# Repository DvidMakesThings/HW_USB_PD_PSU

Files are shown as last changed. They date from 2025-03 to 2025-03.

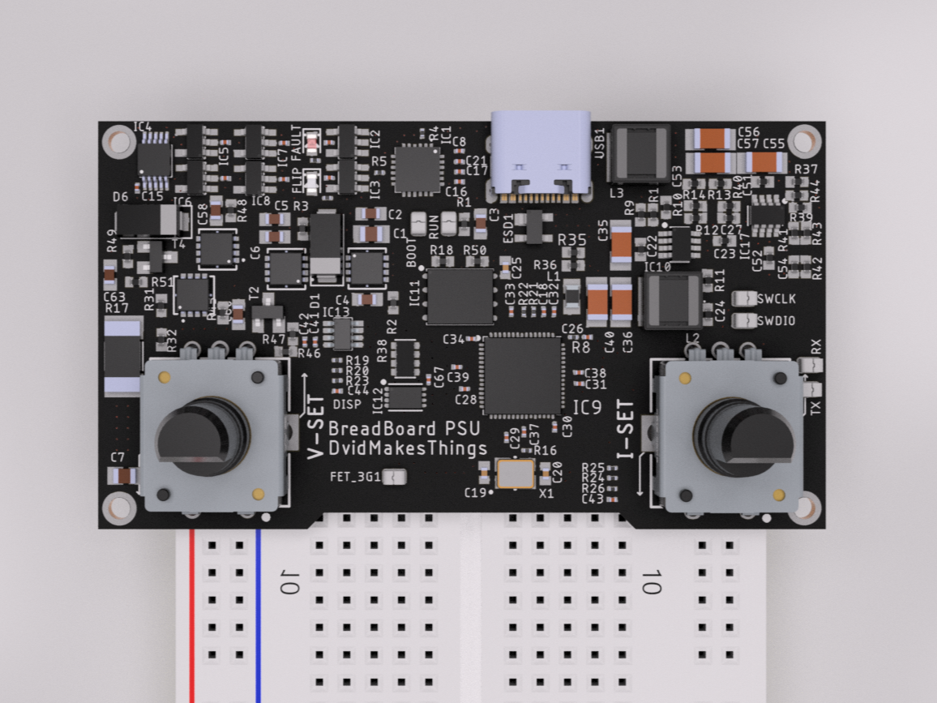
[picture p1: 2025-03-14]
images/USB-PD-PSU-3D-3.png

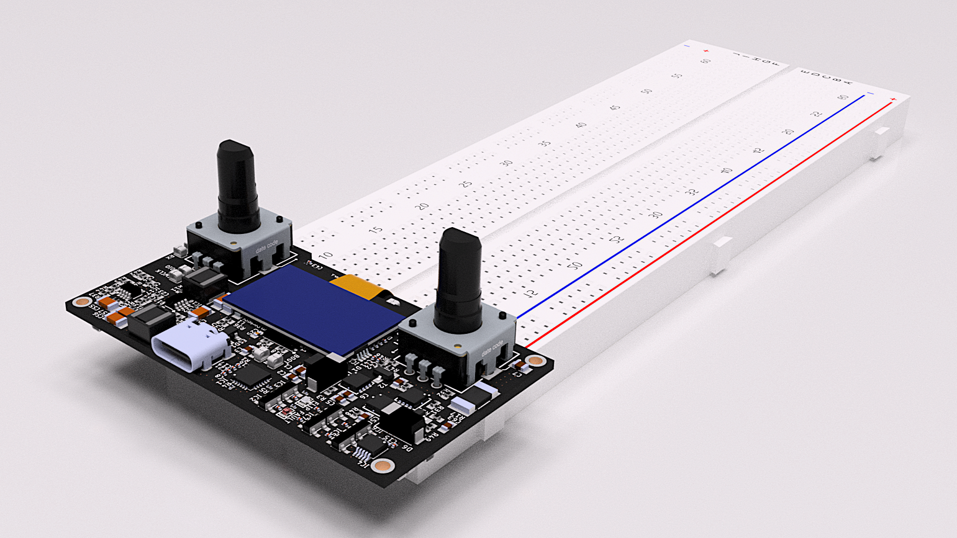
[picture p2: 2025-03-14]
images/USB-PD-PSU-3D-1.png

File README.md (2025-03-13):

# USB-PD-PSU Project

## Contents
This folder contains all the documents related to the USB-PD-PSU project.

## Usage
To use the files in this project, navigate to the respective directories and follow the instructions provided in each document.

## License
This project is licensed under the GPL-3.0 License. See the [LICENSE](LICENSE) file for details.

## Contact
For questions or feedback:
- Email: [s.dvid@hotmail.com](mailto:s.dvid@hotmail.com)
- GitHub: [DvidMakesThings](https://github.com/DvidMakesThings)

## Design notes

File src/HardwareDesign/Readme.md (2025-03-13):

# # USB-PD-PSU Project Hardware Design Files

## Contents
This folder contains the hardware design files for the USB-PD-PSU project. The main components include:
- Schematic diagrams
- PCB layouts
- Bill of Materials (BOM)
- Gerber files

## Usage
To use these hardware design files:
1. Open the schematic diagrams and PCB layouts using EAGLE software.
2. Review the Bill of Materials for required components.
3. Follow the design files to assemble and test the hardware.
4. Use the Gerber files for PCB manufacturing.

## License
This project is licensed under the GPL-3.0 License. See the [LICENSE](LICENSE) file for details.

## Contact
For questions or feedback:
- Email: [s.dvid@hotmail.com](mailto:s.dvid@hotmail.com)
- GitHub: [DvidMakesThings](https://github.com/DvidMakesThings)

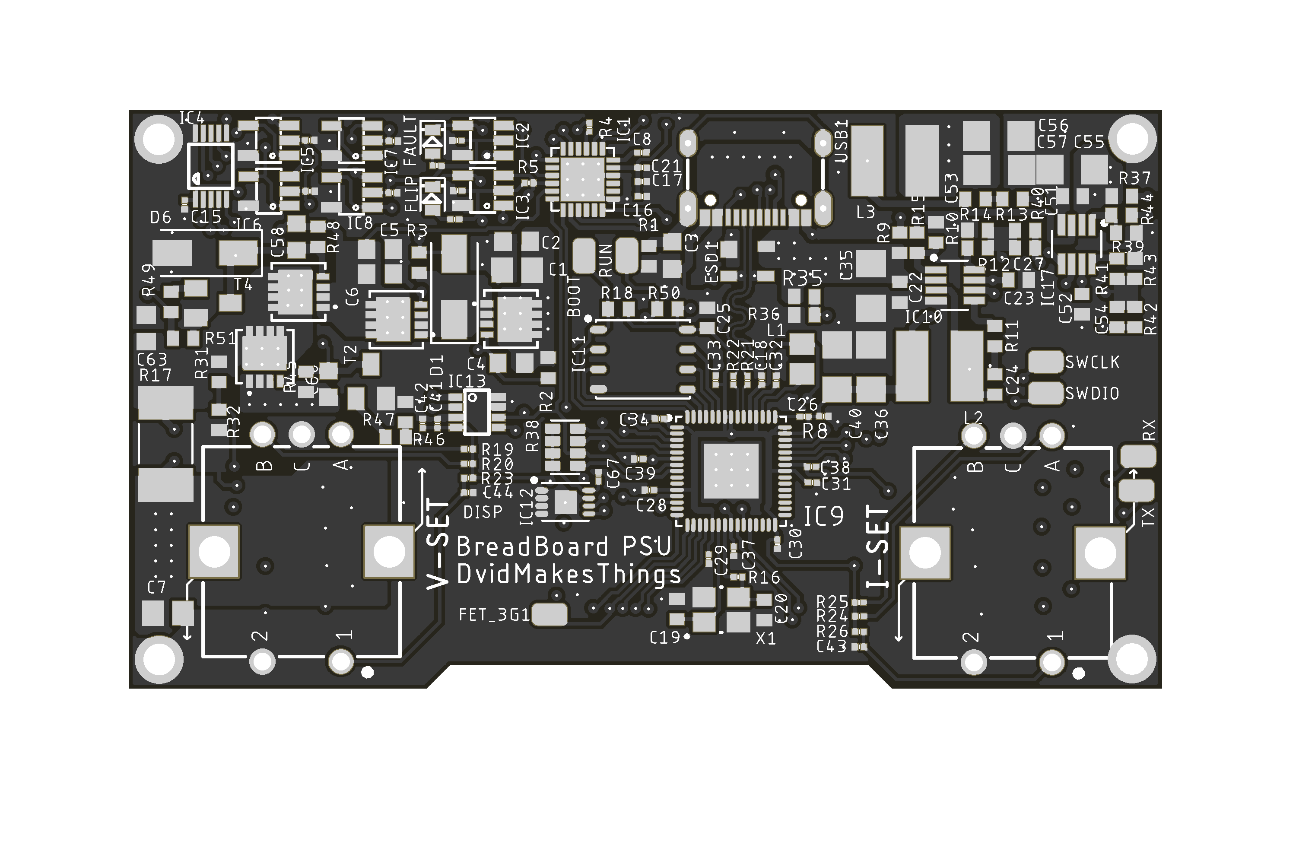
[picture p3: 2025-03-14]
images/USB-PD-PSU-Top.png

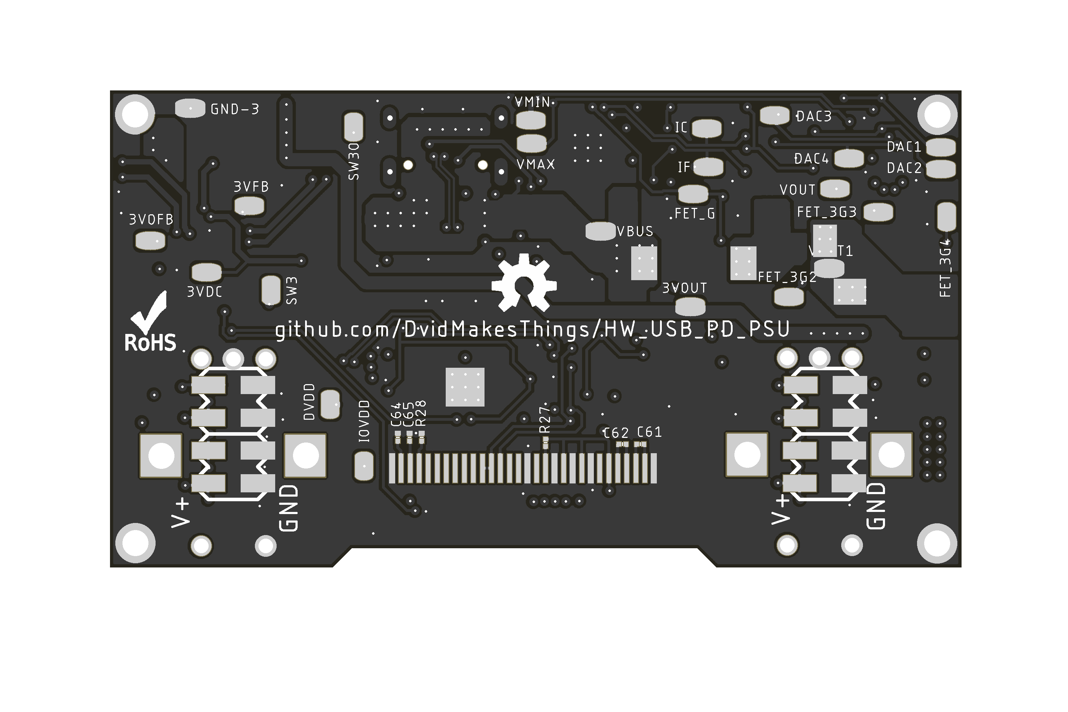
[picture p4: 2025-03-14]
images/USB-PD-PSU-Bottom.png

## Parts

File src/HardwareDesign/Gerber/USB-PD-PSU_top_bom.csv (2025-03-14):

Comment | Designator | Footprint | LCSC Part #
 | IC9 | QFN40P700X700X85-61T340N
 | USB1 | USB-C
0.1R 1% | R17 | 2512
1K | R4 R6 R7 R16 | R0201
1K | R32 R36 | 0402
1M | R1 | 0402
1uF | C4 | C0603
1uF | C8 C21 C42 | 0201
1uF | C58 C60 | C0603
3.3uH LQM21PN3R3MGRD | L1 | 0805
4.2uH | L2 L3 | SRR5228A
4.7K | R5 | R0201
4.7uF | C18 C26 C39 | 0201
4D03WGJ0332T5E | R38 | 742C083103JP
7.5K | R10 R39 | 0402
10K | R2 R18 | 0402
10K | R19 R20 R23 R24 R25 R26 | R0201
10K | R31 R35 R45 R47 R48 R50 R51 | 0402
10R | R11 R40 R46 R49 | 0402
10uF | C1 | C0805
10uF | C15 | 0201
10uF 50V | C6 | C0603
10uF 50V | C7 | C0805
10uF 50V | C63 | C0603
12.7K | R14 R43 | 0402
12MHz | X1 | WE-XTAL_CFPX-180
15pF | C19 C20 | C0402
22uF - 10V | C36 C40 C56 C57 | C1206
22uF 25V | C35 C55 | C1206
27R | R8 R21 R22 | R0201
33K | R12 R41 | 0402
33pF | C27 C54 | 0402
40.2K | R13 R42 | 0402
49.9K | R3 | 0402
100K | R15 R44 | 0402
100nF | C2 C3 | C0603
100nF | C9 C10 C11 C12 C13 C14 C16 C17 | 0201
100nF | C22 C23 C24 | 0402
100nF | C25 | C0402
100nF | C28 C29 C30 C31 C32 C33 C34 C37 C38 C41 C43 C44 | 0201
100nF | C51 C52 C53 | 0402
100nF | C67 | 0201
100nF 50V | C5 | C0603
499K | R9 R37 | 0402
BSS138 | T2 T4 | SOT23
CAT24C512HU5IGT3 | IC12 | SON50P300X200X50-9T130X140N
CHIP-FLAT-B_0603 | FLIP | LEDC1608X55N_FLAT-B
CHIP-FLAT-R_0603 | FAULT | LEDC1608X55N_FLAT-R
CYPD3177 | IC1 | QFN24
DMP3013SFV | MOSFET1 MOSFET2 MOSFET3 MOSFET4 | POWERDI3333-8_UX_DIO-L
INA219BIDCNT | IC13 | SOT23-8
MCP4728 | IC4 | MSOP10
MCP6001RT-I/OT | IC2 IC3 IC5 IC6 IC7 IC8 | SOT23-5
MP2315S | IC10 IC17 | SOT65P280X110-8N
SMBJ5929B | D1 D6 | DIOM5226X290N
SP0503BAHTG-ES | ESD1 | SOT143
TP | BOOT FET_3G1 RUN RX SWCLK SWDIO TX | TP
W25Q128JVPIQ | IC11 | SON127P600X500X75-8N

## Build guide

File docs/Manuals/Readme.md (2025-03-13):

# USB-PD-PSU Project Manuals

## Contents
- Manuals

## Usage
This folder contains documentation and manuals for the USB-PD-PSU project.

## License
This project is licensed under the GPL-3.0 License. See the [LICENSE](LICENSE) file for details.

## Contact
For questions or feedback:
- Email: [s.dvid@hotmail.com](mailto:s.dvid@hotmail.com)
- GitHub: [DvidMakesThings](https://github.com/DvidMakesThings)

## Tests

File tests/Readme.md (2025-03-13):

# USB-PD-PSU Project Test files

This folder contains the main test files for the USB-PD-PSU project.

## Contents
- Various test scripts and files for the USB-PD-PSU project.

## Usage
1. Clone the repository.
2. Navigate to this folder.
3. Run the test scripts as needed.

## License
This project is licensed under the GPL-3.0 License. See the [LICENSE](LICENSE) file for details.

## Contact
For questions or feedback:
- Email: [s.dvid@hotmail.com](mailto:s.dvid@hotmail.com)
- GitHub: [DvidMakesThings](https://github.com/DvidMakesThings)

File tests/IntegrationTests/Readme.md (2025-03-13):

# # USB-PD-PSU Project Integration Tests

This folder contains integration tests for the USB-PD-PSU project.

## Contents

- Various integration test scripts and resources.

## Usage

1. Clone the repository.
2. Navigate to this folder.
3. Run the integration tests using your preferred testing framework.

## License
This project is licensed under the GPL-3.0 License. See the [LICENSE](LICENSE) file for details.

## Contact
For questions or feedback:
- Email: [s.dvid@hotmail.com](mailto:s.dvid@hotmail.com)
- GitHub: [DvidMakesThings](https://github.com/DvidMakesThings)

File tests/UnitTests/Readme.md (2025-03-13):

# USB-PD-PSU Project Unit Tests

## Contents
This folder contains unit tests for the USB-PD-PSU project.

## Usage
To run the unit tests, navigate to this directory and execute the test scripts using your preferred testing framework.

## License
This project is licensed under the GPL-3.0 License. See the [LICENSE](LICENSE) file for details.

## Contact
For questions or feedback:
- Email: [s.dvid@hotmail.com](mailto:s.dvid@hotmail.com)
- GitHub: [DvidMakesThings](https://github.com/DvidMakesThings)

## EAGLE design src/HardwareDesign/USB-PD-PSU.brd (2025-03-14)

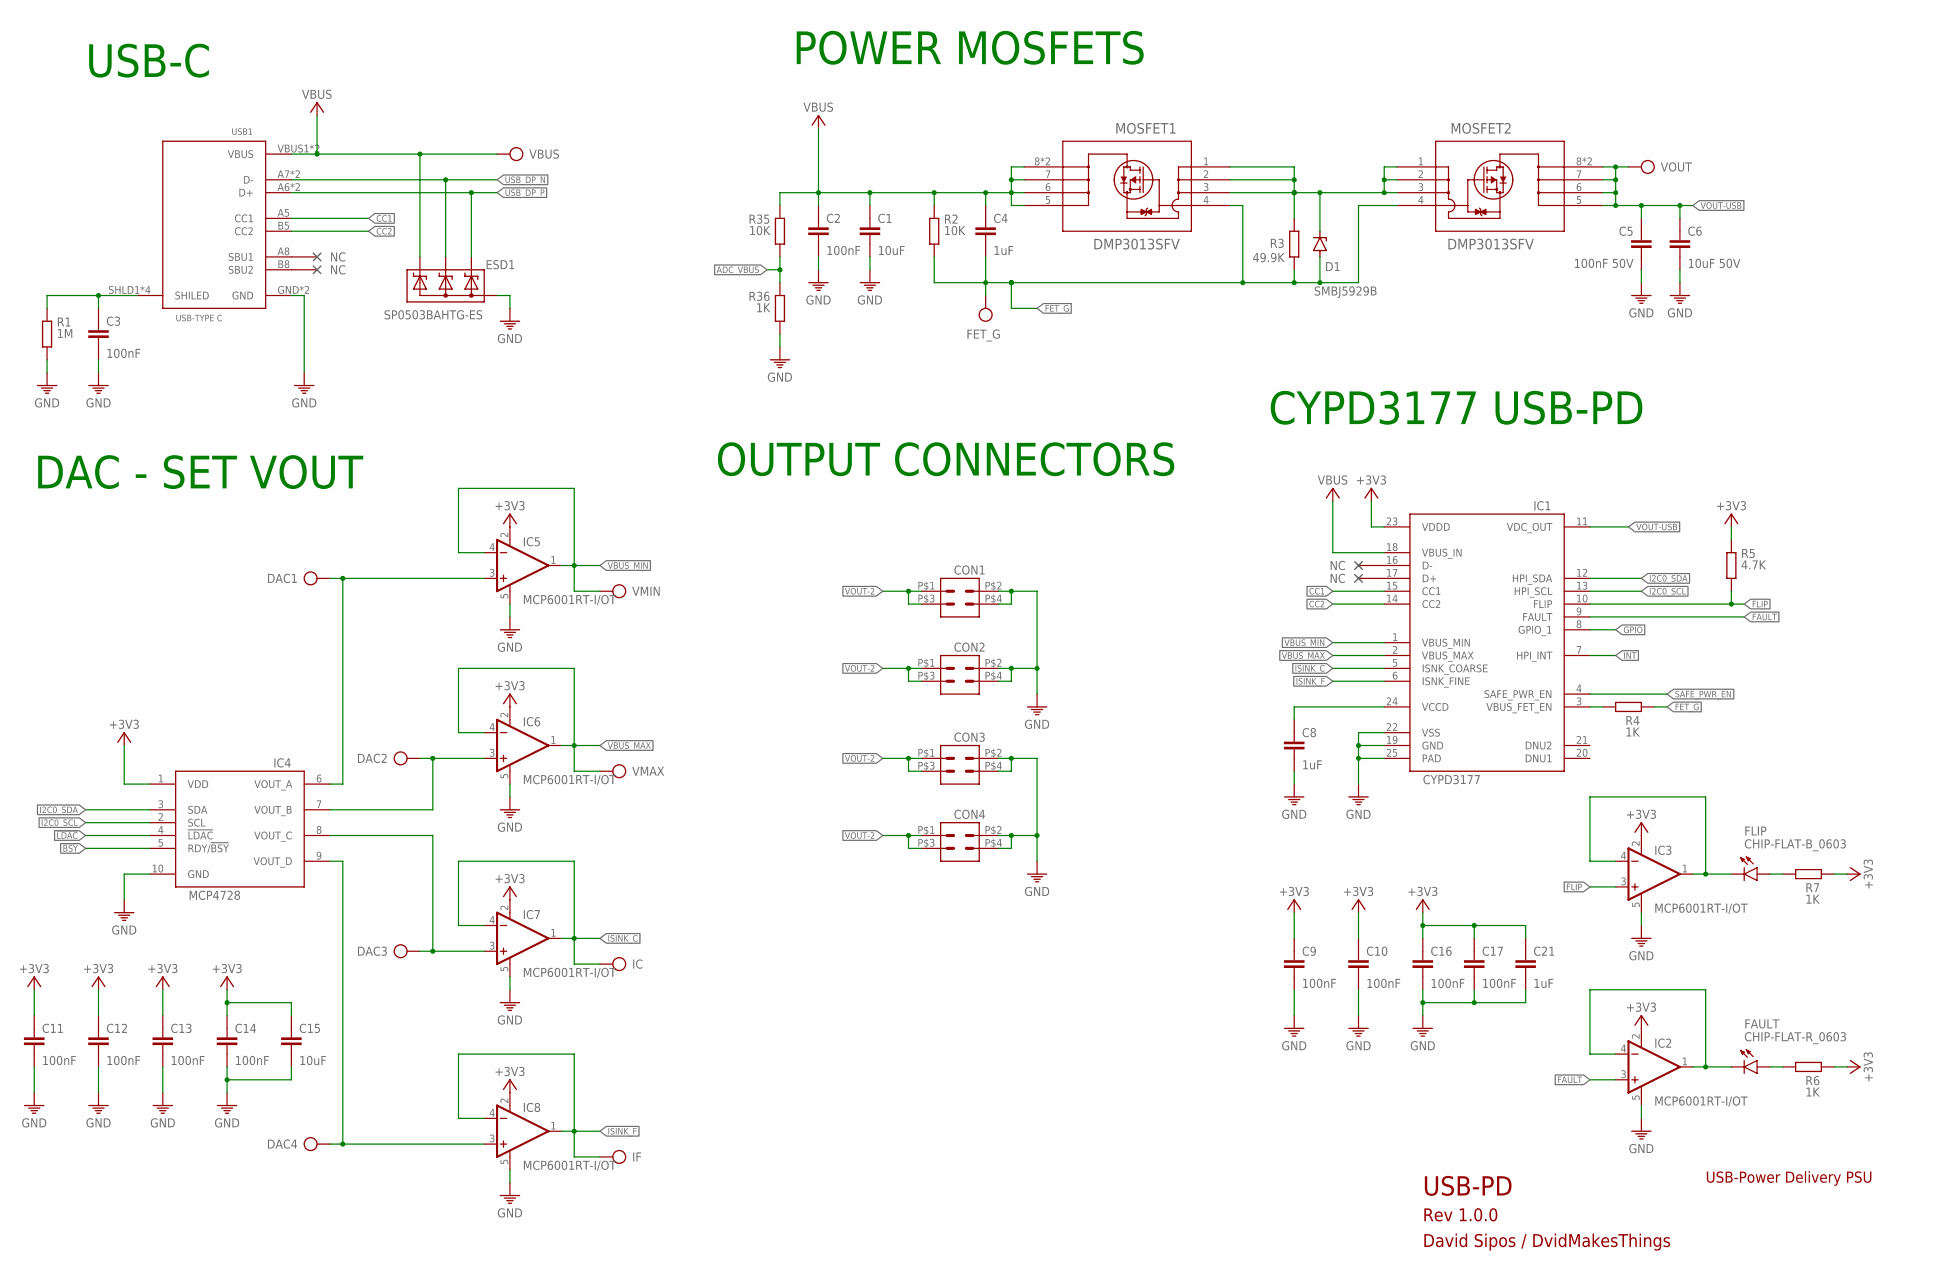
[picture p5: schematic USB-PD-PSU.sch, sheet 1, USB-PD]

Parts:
C1: 10uF; C0805
C2, C3: 100nF; C0603
C4: 1uF; C0603
C5: 100nF 50V; C0603
C6: 10uF 50V; C0603
C8, C21: 1uF; 0201
C9, C10, C11, C12, C13, C14, C16, C17: 100nF; 0201
C15: 10uF; 0201
CON1, CON2, CON3, CON4: CON-2X2SMD; 2X2_SMD
D1: SMBJ5929B; DIOM5226X290N
DAC1, DAC2, DAC3, DAC4: TP
ESD1: SP0503BAHTG-ES; SOT143
FAULT: CHIP-FLAT-R_0603; LEDC1608X55N_FLAT-R
FET_G: TP
FLIP: CHIP-FLAT-B_0603; LEDC1608X55N_FLAT-B
IC: TP
IC1: CYPD3177; QFN24
IC2, IC3, IC5, IC6, IC7, IC8: MCP6001RT-I/OT; SOT23-5
IC4: MCP4728; MSOP10
IF: TP
MOSFET1, MOSFET2: DMP3013SFV; POWERDI3333-8_UX_DIO-L
R1: 1M; 0402
R2, R35: 10K; 0402
R3: 49.9K; 0402
R4, R6, R7: 1K; R0201
R5: 4.7K; R0201
R36: 1K; 0402
USB1: USB_C-THT; USB-C
VBUS: TP
VMAX: TP
VMIN: TP
VOUT: TP

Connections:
!BSY: IC4.5 (RDY/!BSY); also elsewhere on the board
!LDAC: IC4.4 (!LDAC); also elsewhere on the board
+3V3: C9.1, C10.1, C11.1, C12.1, C13.1, C14.1, C15.1, C16.1, C17.1, C21.1, IC1.23 (VDDD), IC2.2 (V+), IC3.2 (V+), IC4.1 (VDD), IC5.2 (V+), IC6.2 (V+), IC7.2 (V+), IC8.2 (V+), R5.1, R6.1, R7.1; also elsewhere on the board
ADC_VBUS: R35.2, R36.1; also elsewhere on the board
CC1: IC1.15 (CC1), USB1.A5 (CC1)
CC2: IC1.14 (CC2), USB1.B5 (CC2)
FAULT: IC1.9 (FAULT), IC2.3 (+IN); also elsewhere on the board
FET_G: C4.2, D1.2 (A), FET_G.TP, MOSFET1.4 (G), MOSFET2.4 (G), R2.2, R3.2, R4.1
FLIP: IC1.10 (FLIP), IC3.3 (+IN), R5.2; also elsewhere on the board
GND: C1.2, C2.2, C3.2, C5.2, C6.2, C8.2, C9.2, C10.2, C11.2, C12.2, C13.2, C14.2, C15.2, C16.2, C17.2, C21.2, CON1.P$2 (2), CON1.P$4 (4), CON2.P$2 (2), CON2.P$4 (4), CON3.P$2 (2), CON3.P$4 (4), CON4.P$2 (2), CON4.P$4 (4), ESD1.1 (A), IC1.19 (GND), IC1.22 (VSS), IC1.25 (PAD), IC2.5 (V-), IC3.5 (V-), IC4.10 (GND), IC5.5 (V-), IC6.5 (V-), IC7.5 (V-), IC8.5 (V-), R1.2, R36.2, USB1.GND, USB1.GND2 (GND); also elsewhere on the board
GPIO: IC1.8 (GPIO_1)
I2C0_SCL: IC1.13 (HPI_SCL), IC4.2 (SCL); also elsewhere on the board
I2C0_SDA: IC1.12 (HPI_SDA), IC4.3 (SDA); also elsewhere on the board
INT: IC1.7 (HPI_INT); also elsewhere on the board
ISINK_C: IC.TP, IC1.5 (ISNK_COARSE), IC7.1 (OUT), IC7.4 (-IN)
ISINK_F: IC1.6 (ISNK_FINE), IC8.1 (OUT), IC8.4 (-IN), IF.TP
unnamed: C3.1, R1.1, USB1.SHLD1 (SHILED), USB1.SHLD2 (SHILED), USB1.SHLD3 (SHILED), USB1.SHLD4 (SHILED)
unnamed: FLIP.C, IC3.1 (OUT), IC3.4 (-IN)
unnamed: C8.1, IC1.24 (VCCD)
unnamed: IC1.3 (VBUS_FET_EN), R4.2
unnamed: D1.1 (C), MOSFET1.1 (S_2), MOSFET1.2 (S_3), MOSFET1.3 (S), MOSFET2.1 (S_2), MOSFET2.2 (S_3), MOSFET2.3 (S), R3.1
unnamed: FAULT.C, IC2.1 (OUT), IC2.4 (-IN)
unnamed: FLIP.A, R7.2
unnamed: FAULT.A, R6.2
unnamed: DAC1.TP, IC4.6 (VOUT_A), IC5.3 (+IN)
unnamed: DAC2.TP, IC4.7 (VOUT_B), IC6.3 (+IN)
unnamed: DAC3.TP, IC4.8 (VOUT_C), IC7.3 (+IN)
unnamed: DAC4.TP, IC4.9 (VOUT_D), IC8.3 (+IN)
SAFE_PWR_EN: IC1.4 (SAFE_PWR_EN)
USB_DP_N: ESD1.3 (C2), USB1.A7 (D-), USB1.B7 (D-); also elsewhere on the board
USB_DP_P: ESD1.2 (C1), USB1.A6 (D+), USB1.B6 (D+); also elsewhere on the board
VBUS: C1.1, C2.1, C4.1, ESD1.4 (C3), IC1.18 (VBUS_IN), MOSFET1.5 (D_2), MOSFET1.6 (D_3), MOSFET1.7 (D_4), MOSFET1.8 (D), MOSFET1.9 (D), R2.1, R35.1, USB1.VBUS1 (VBUS), USB1.VBUS2 (VBUS), VBUS.TP; also elsewhere on the board
VBUS_MAX: IC1.2 (VBUS_MAX), IC6.1 (OUT), IC6.4 (-IN), VMAX.TP
VBUS_MIN: IC1.1 (VBUS_MIN), IC5.1 (OUT), IC5.4 (-IN), VMIN.TP
VOUT-2: CON1.P$1 (1), CON1.P$3 (3), CON2.P$1 (1), CON2.P$3 (3), CON3.P$1 (1), CON3.P$3 (3), CON4.P$1 (1), CON4.P$3 (3); also elsewhere on the board
VOUT-USB: C5.1, C6.1, IC1.11 (VDC_OUT), MOSFET2.5 (D_2), MOSFET2.6 (D_3), MOSFET2.7 (D_4), MOSFET2.8 (D), MOSFET2.9 (D), VOUT.TP; also elsewhere on the board

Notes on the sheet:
CYPD3177 USB-PD
USB-C
POWER MOSFETS
DAC - SET VOUT
USB-PD
Rev 1.0.0
David Sipos / DvidMakesThings
USB-Power Delivery PSU
OUTPUT CONNECTORS

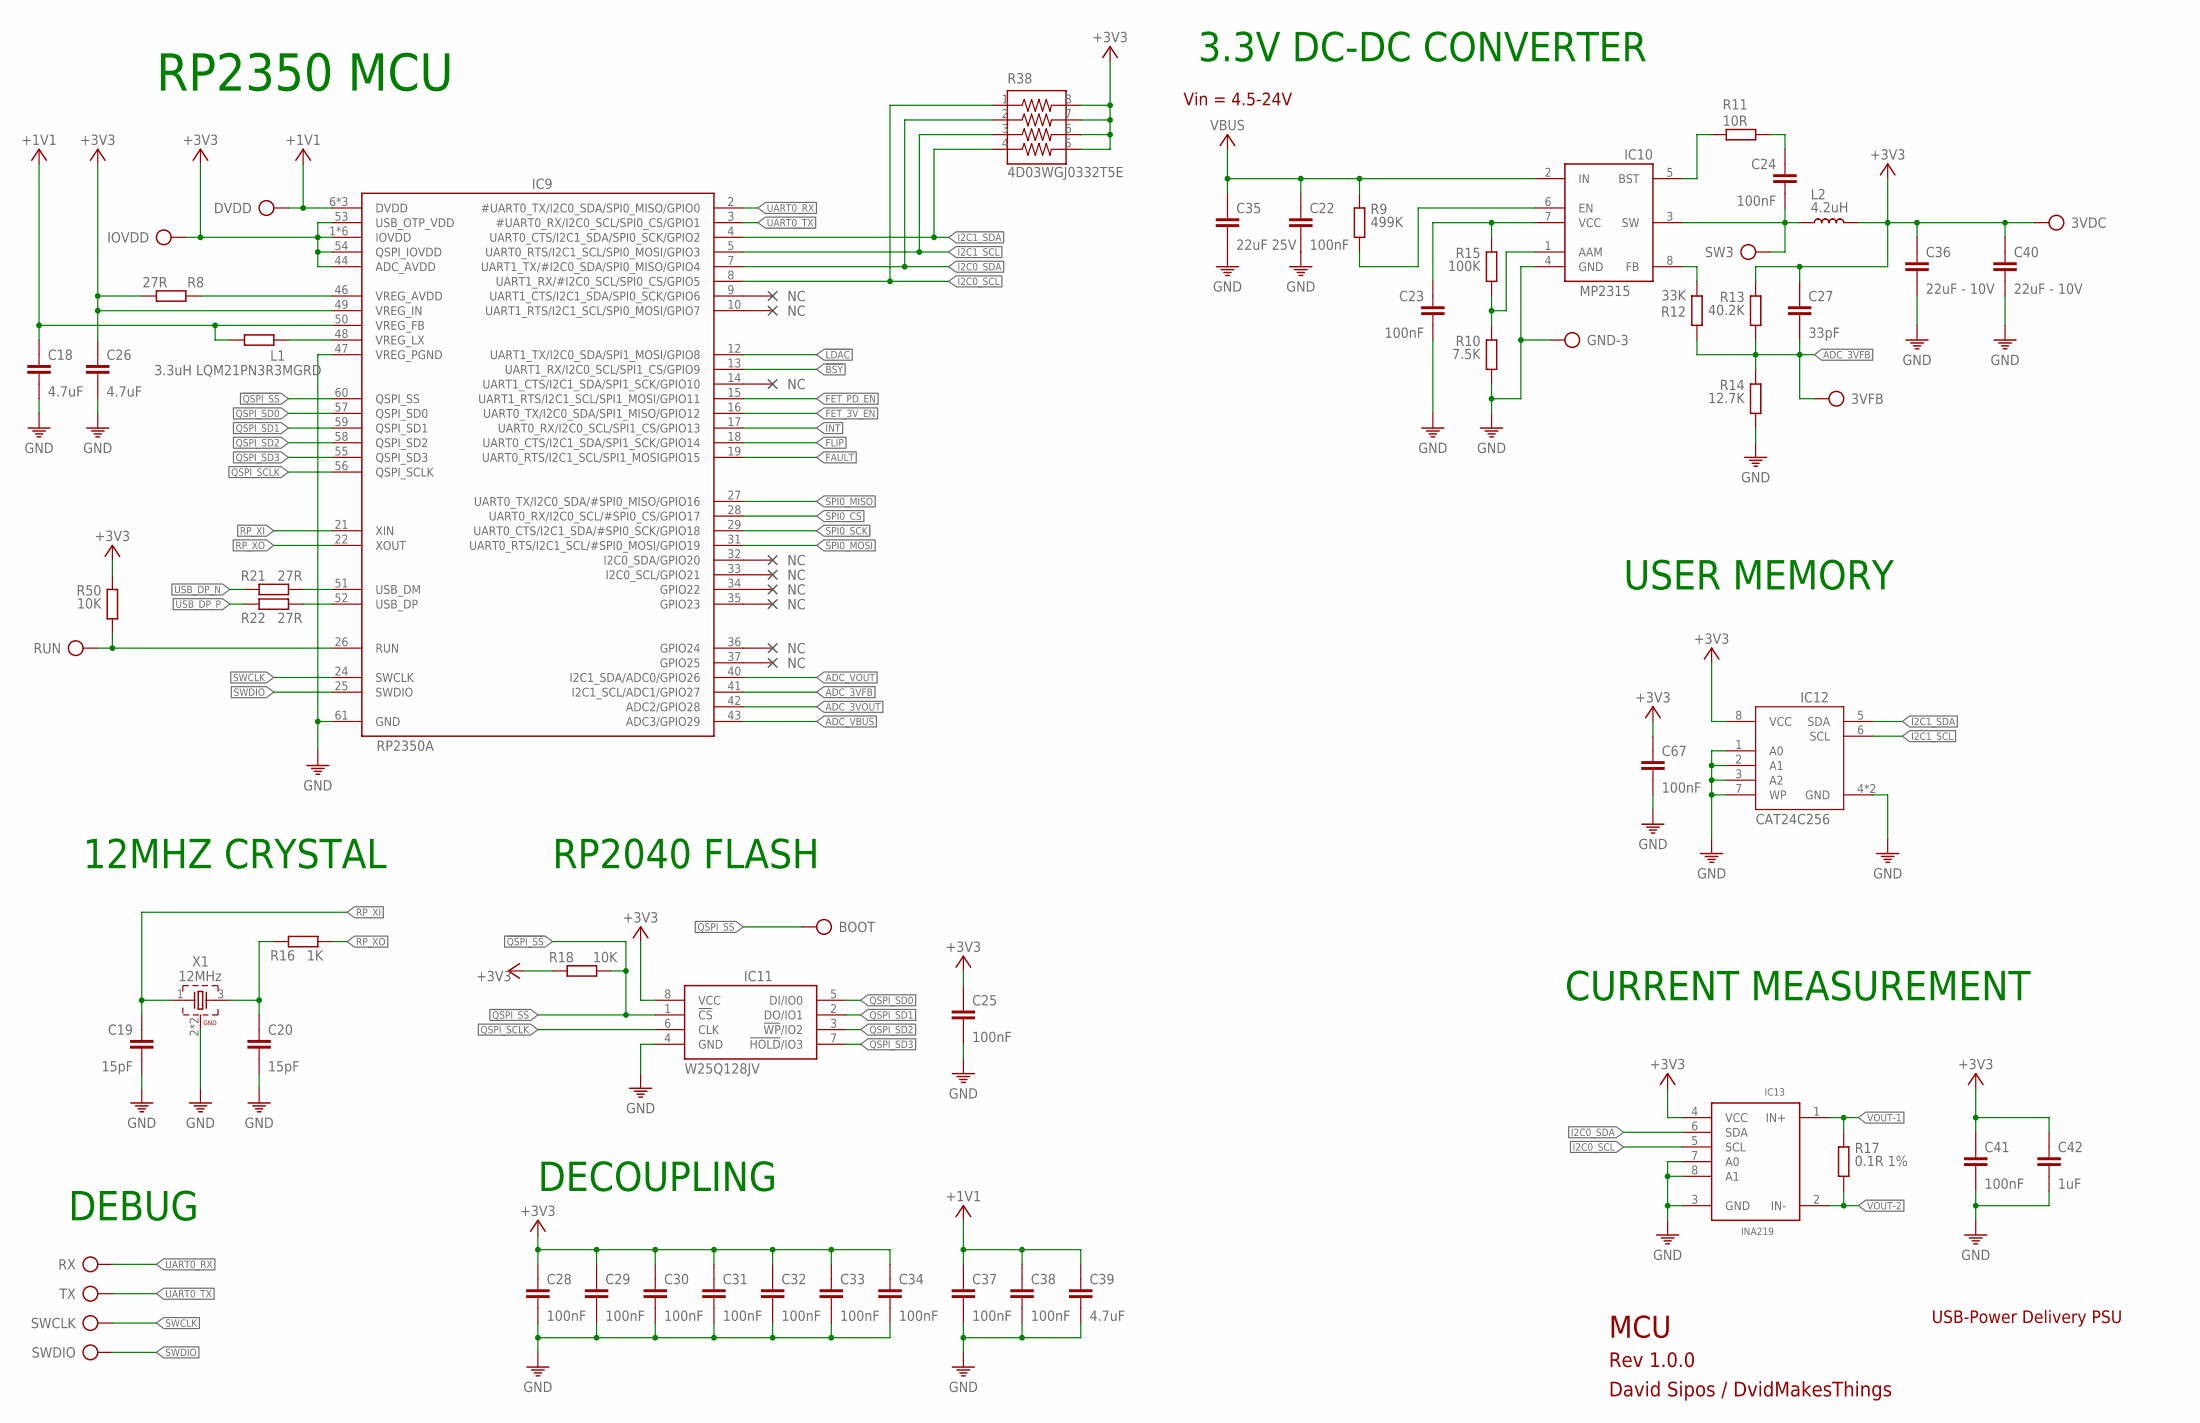
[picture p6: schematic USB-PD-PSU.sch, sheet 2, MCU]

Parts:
3VDC, 3VFB: TP
BOOT: TP
C18, C26, C39: 4.7uF; 0201
C19, C20: 15pF; C0402
C22, C23, C24: 100nF; 0402
C25: 100nF; C0402
C27: 33pF; 0402
C28, C29, C30, C31, C32, C33, C34, C37, C38, C41, C67: 100nF; 0201
C35: 22uF 25V; C1206
C36, C40: 22uF - 10V; C1206
C42: 1uF; 0201
DVDD: TP
GND-3: TP
IC9: RP2350AA; QFN40P700X700X85-61T340N
IC10: MP2315S; SOT65P280X110-8N
IC11: W25Q128JVPIQ; SON127P600X500X75-8N
IC12: CAT24C512HU5IGT3; SON50P300X200X50-9T130X140N
IC13: INA219BIDCNT; SOT23-8
IOVDD: TP
L1: 3.3uH LQM21PN3R3MGRD; 0805
L2: 4.2uH; SRR5228A
R8, R21, R22: 27R; R0201
R9: 499K; 0402
R10: 7.5K; 0402
R11: 10R; 0402
R12: 33K; 0402
R13: 40.2K; 0402
R14: 12.7K; 0402
R15: 100K; 0402
R16: 1K; R0201
R17: 0.1R 1%; 2512
R18, R50: 10K; 0402
R38: 4D03WGJ0332T5E; 742C083103JP
RUN: TP
RX: TP
SW3: TP
SWCLK: TP
SWDIO: TP
TX: TP
X1: 12MHz; WE-XTAL_CFPX-180

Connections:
!BSY: IC9.13 (UART1_RX/I2C0_SCL/SPI1_CS/GPIO9); also elsewhere on the board
!LDAC: IC9.12 (UART1_TX/I2C0_SDA/SPI1_MOSI/GPIO8); also elsewhere on the board
!QSPI_SS: BOOT.TP, IC9.60 (QSPI_SS), IC11.1 (!CS), R18.1
+1V1: C18.1, C37.1, C38.1, C39.1, DVDD.TP, IC9.6 (DVDD), IC9.23 (DVDD), IC9.39 (DVDD), IC9.50 (VREG_FB), L1.2
+3V3: 3VDC.TP, C25.1, C26.1, C27.1, C28.1, C29.1, C30.1, C31.1, C32.1, C33.1, C34.1, C36.1, C40.1, C41.1, C42.1, C67.1, IC9.1 (IOVDD), IC9.11 (IOVDD), IC9.20 (IOVDD), IC9.30 (IOVDD), IC9.38 (IOVDD), IC9.44 (ADC_AVDD), IC9.45 (IOVDD), IC9.49 (VREG_IN), IC9.53 (USB_OTP_VDD), IC9.54 (QSPI_IOVDD), IC11.8 (VCC), IC12.8 (VCC), IC13.4 (VCC), IOVDD.TP, L2.2, R8.2, R13.1, R18.2, R38.5, R38.6, R38.7, R38.8, R50.1; also elsewhere on the board
ADC_3VFB: 3VFB.TP, C27.2, IC9.41 (I2C1_SCL/ADC1/GPIO27), R12.2, R13.2, R14.1
ADC_3VOUT: IC9.42 (ADC2/GPIO28); also elsewhere on the board
ADC_VBUS: IC9.43 (ADC3/GPIO29); also elsewhere on the board
ADC_VOUT: IC9.40 (I2C1_SDA/ADC0/GPIO26); also elsewhere on the board
FAULT: IC9.19 (UART0_RTS/I2C1_SCL/SPI1_MOSIGPIO15); also elsewhere on the board
FET_3V_EN: IC9.16 (UART0_TX/I2C0_SDA/SPI1_MISO/GPIO12); also elsewhere on the board
FET_PD_EN: IC9.15 (UART1_RTS/I2C1_SCL/SPI1_MOSI/GPIO11); also elsewhere on the board
FLIP: IC9.18 (UART0_CTS/I2C1_SDA/SPI1_SCK/GPIO14); also elsewhere on the board
GND: C18.2, C19.2, C20.2, C22.2, C23.2, C25.2, C26.2, C28.2, C29.2, C30.2, C31.2, C32.2, C33.2, C34.2, C35.2, C36.2, C37.2, C38.2, C39.2, C40.2, C41.2, C42.2, C67.2, GND-3.TP, IC9.47 (VREG_PGND), IC9.61 (GND), IC10.4 (GND), IC11.4 (GND), IC12.1 (A0), IC12.2 (A1), IC12.3 (A2), IC12.4 (GND), IC12.7 (WP), IC12.9 (GND), IC13.3 (GND), IC13.7 (A0), IC13.8 (A1), R10.2, R14.2, X1.2 (GND), X1.4 (GND); also elsewhere on the board
I2C0_SCL: IC9.8 (UART1_RX/#I2C0_SCL/SPI0_CS/GPIO5), IC13.5 (SCL), R38.1; also elsewhere on the board
I2C0_SDA: IC9.7 (UART1_TX/#I2C0_SDA/SPI0_MISO/GPIO4), IC13.6 (SDA), R38.2; also elsewhere on the board
I2C1_SCL: IC9.5 (UART0_RTS/I2C1_SCL/SPI0_MOSI/GPIO3), IC12.6 (SCL), R38.3; also elsewhere on the board
I2C1_SDA: IC9.4 (UART0_CTS/I2C1_SDA/SPI0_SCK/GPIO2), IC12.5 (SDA), R38.4; also elsewhere on the board
INT: IC9.17 (UART0_RX/I2C0_SCL/SPI1_CS/GPIO13); also elsewhere on the board
MCU_DP_N: IC9.51 (USB_DM), R21.2
MCU_DP_P: IC9.52 (USB_DP), R22.2
unnamed: C20.1, R16.1, X1.3 (2)
unnamed: IC9.46 (VREG_AVDD), R8.1
unnamed: IC9.48 (VREG_LX), L1.1
unnamed: IC9.26 (RUN), R50.2, RUN.TP
unnamed: IC10.5 (BST), R11.2
unnamed: IC10.8 (FB), R12.1
unnamed: C24.1, R11.1
unnamed: IC10.6 (EN), R9.2
unnamed: C23.1, IC10.7 (VCC), R15.1
unnamed: IC10.1 (AAM), R10.1, R15.2
QSPI_SCLK: IC9.56 (QSPI_SCLK), IC11.6 (CLK)
QSPI_SD0: IC9.57 (QSPI_SD0), IC11.5 (DI/IO0)
QSPI_SD1: IC9.59 (QSPI_SD1), IC11.2 (DO/IO1)
QSPI_SD2: IC9.58 (QSPI_SD2), IC11.3 (!WP!/IO2)
QSPI_SD3: IC9.55 (QSPI_SD3), IC11.7 (!HOLD!/IO3)
RP_XI: C19.1, IC9.21 (XIN), X1.1
RP_XO: IC9.22 (XOUT), R16.2
SPI0_CS: IC9.28 (UART0_RX/I2C0_SCL/#SPI0_CS/GPIO17)
SPI0_MISO: IC9.27 (UART0_TX/I2C0_SDA/#SPI0_MISO/GPIO16)
SPI0_MOSI: IC9.31 (UART0_RTS/I2C1_SCL/#SPI0_MOSI/GPIO19)
SPI0_SCK: IC9.29 (UART0_CTS/I2C1_SDA/#SPI0_SCK/GPIO18)
SW3: C24.2, IC10.3 (SW), L2.1, SW3.TP
SWCLK: IC9.24 (SWCLK), SWCLK.TP
SWDIO: IC9.25 (SWDIO), SWDIO.TP
UART0_RX: IC9.2 (#UART0_TX/I2C0_SDA/SPI0_MISO/GPIO0), RX.TP
UART0_TX: IC9.3 (#UART0_RX/I2C0_SCL/SPI0_CS/GPIO1), TX.TP
USB_DP_N: R21.1; also elsewhere on the board
USB_DP_P: R22.1; also elsewhere on the board
VBUS: C22.1, C35.1, IC10.2 (IN), R9.1; also elsewhere on the board
VOUT-1: IC13.1 (IN+), R17.1; also elsewhere on the board
VOUT-2: IC13.2 (IN-), R17.2; also elsewhere on the board

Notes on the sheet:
DECOUPLING
12MHZ CRYSTAL
RP2350 MCU
RP2040 FLASH
USER MEMORY
DEBUG
MCU
Rev 1.0.0
David Sipos / DvidMakesThings
USB-Power Delivery PSU
3.3V DC-DC CONVERTER
Vin = 4.5-24V
CURRENT MEASUREMENT

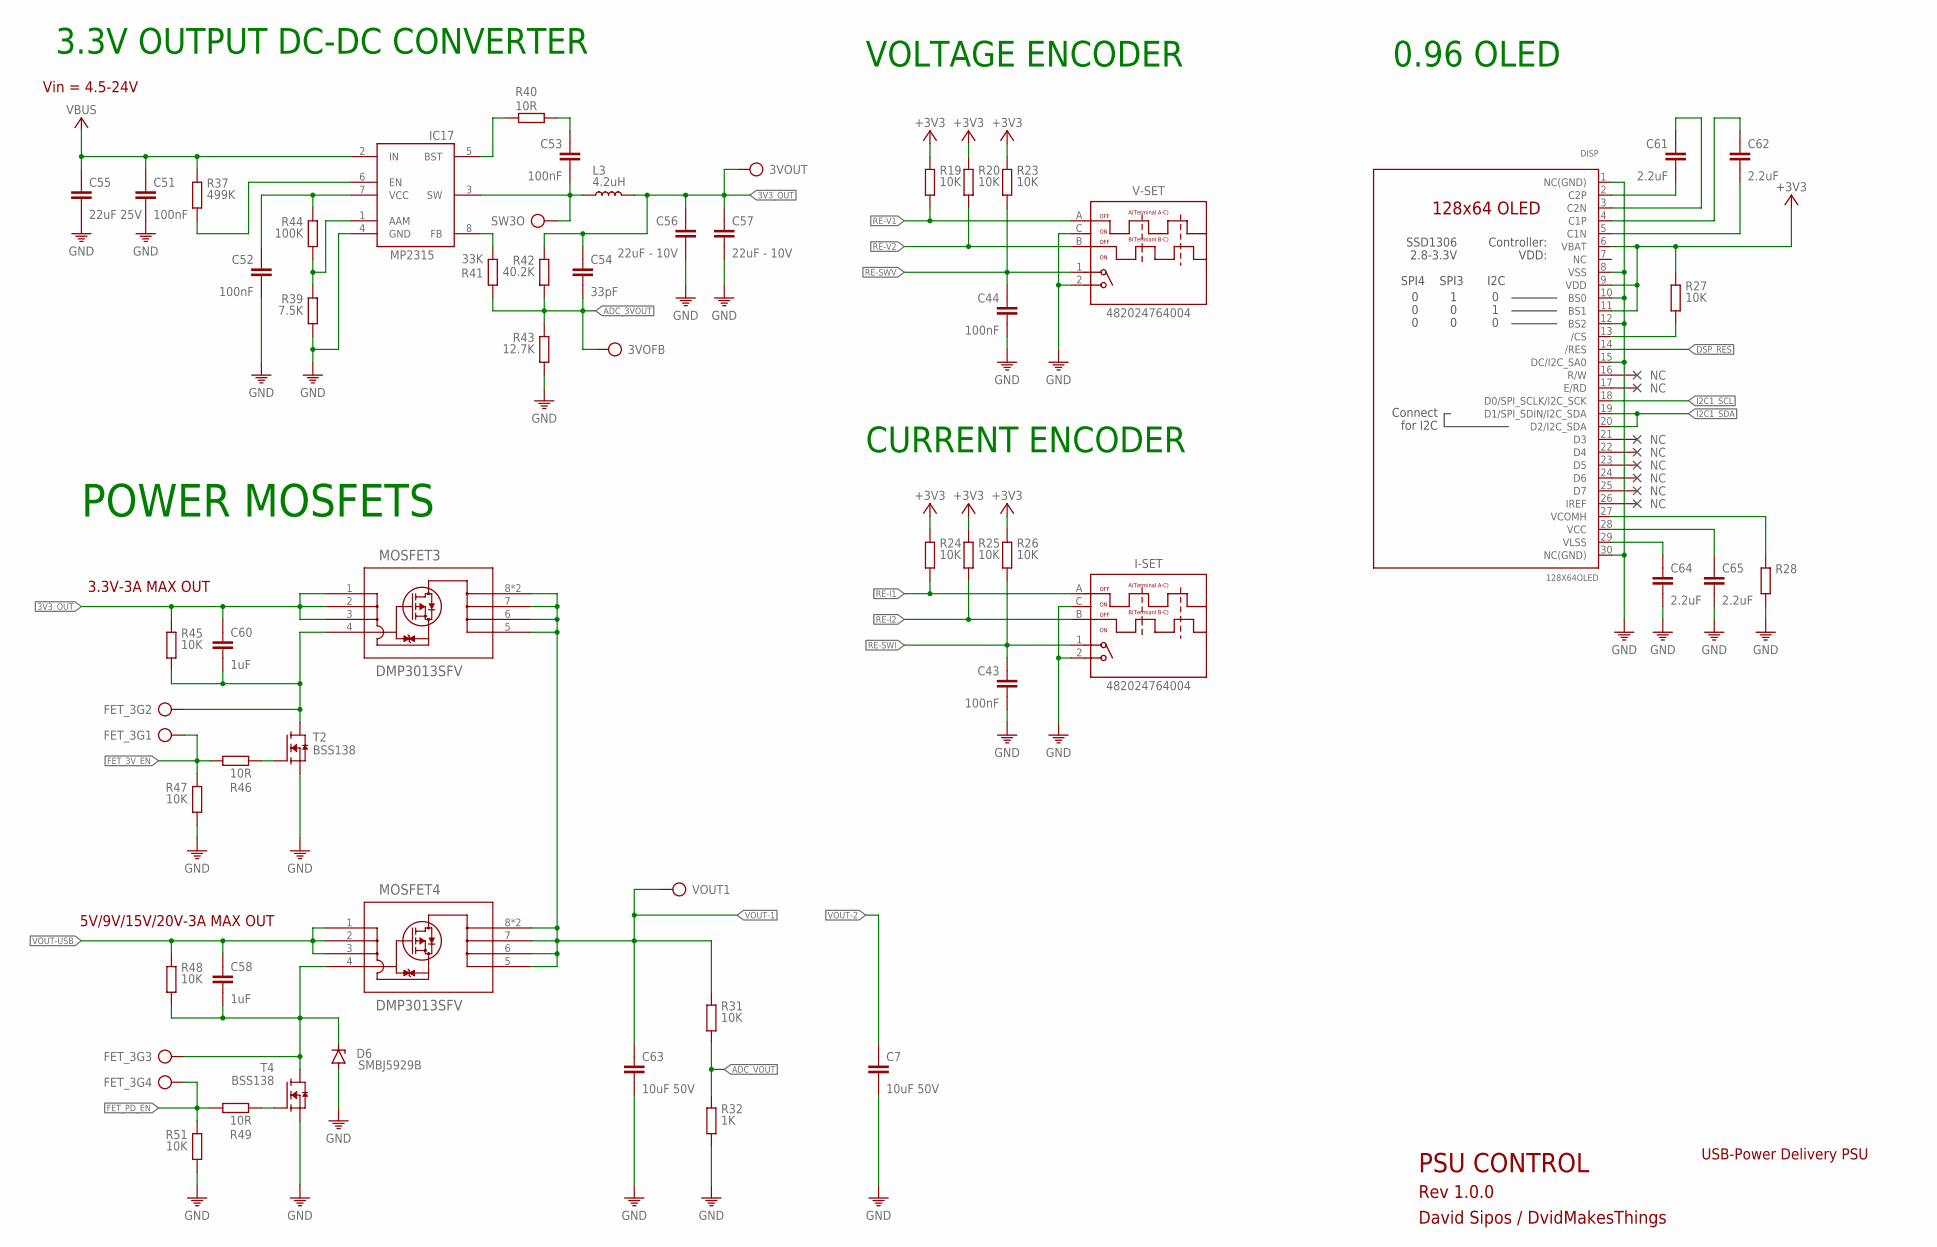
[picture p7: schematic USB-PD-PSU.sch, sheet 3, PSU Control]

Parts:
3VOFB, 3VOUT: TP
C7: 10uF 50V; C0805
C43, C44: 100nF; 0201
C51, C52, C53: 100nF; 0402
C54: 33pF; 0402
C55: 22uF 25V; C1206
C56, C57: 22uF - 10V; C1206
C58, C60: 1uF; C0603
C61, C62, C64, C65: 2.2uF; 0201
C63: 10uF 50V; C0603
D6: SMBJ5929B; DIOM5226X290N
DISP: 128X64OLED; UG2864
FET_3G1, FET_3G2, FET_3G3, FET_3G4: TP
I-SET: 482024764004; WS-ENTV_482024764004
IC17: MP2315S; SOT65P280X110-8N
L3: 4.2uH; SRR5228A
MOSFET3, MOSFET4: DMP3013SFV; POWERDI3333-8_UX_DIO-L
R19, R20, R23, R24, R25, R26, R27: 10K; R0201
R28: R0201
R31, R45, R47, R48, R51: 10K; 0402
R32: 1K; 0402
R37: 499K; 0402
R39: 7.5K; 0402
R40, R46, R49: 10R; 0402
R41: 33K; 0402
R42: 40.2K; 0402
R43: 12.7K; 0402
R44: 100K; 0402
SW3O: TP
T2, T4: BSS138; SOT23
V-SET: 482024764004; WS-ENTV_482024764004
VOUT1: TP

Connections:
3V3_OUT: 3VOUT.TP, C54.1, C56.1, C57.1, C60.1, L3.2, MOSFET3.1 (S_2), MOSFET3.2 (S_3), MOSFET3.3 (S), R42.1, R45.1
+3V3: DISP.6 (VBAT), DISP.9 (VDD), DISP.11 (BS1), R19.1, R20.1, R23.1, R24.1, R25.1, R26.1, R27.1; also elsewhere on the board
ADC_3VOUT: 3VOFB.TP, C54.2, R41.2, R42.2, R43.1; also elsewhere on the board
ADC_VOUT: R31.2, R32.1; also elsewhere on the board
DSP_RES: DISP.14 (/RES)
FET_3V_EN: FET_3G1.TP, R46.1, R47.1; also elsewhere on the board
FET_G1: C60.2, FET_3G2.TP, MOSFET3.4 (G), R45.2, T2.3 (D)
FET_G2: C58.2, D6.1 (C), FET_3G3.TP, MOSFET4.4 (G), R48.2, T4.3 (D)
FET_PD_EN: FET_3G4.TP, R49.1, R51.1; also elsewhere on the board
GND: C7.2, C43.2, C44.2, C51.2, C52.2, C55.2, C56.2, C57.2, C63.2, C64.2, C65.2, D6.2 (A), DISP.1 (NC(GND)), DISP.8 (VSS), DISP.10 (BS0), DISP.12 (BS2), DISP.15 (DC/I2C_SA0), DISP.30 (NC(GND)), I-SET.2, I-SET.C (COM), IC17.4 (GND), R28.2, R32.2, R39.2, R43.2, R47.2, R51.2, T2.2 (S), T4.2 (S), V-SET.2, V-SET.C (COM); also elsewhere on the board
I2C1_SCL: DISP.18 (D0/SPI_SCLK/I2C_SCK); also elsewhere on the board
I2C1_SDA: DISP.19 (D1/SPI_SDIN/I2C_SDA), DISP.20 (D2/I2C_SDA); also elsewhere on the board
unnamed: C61.2, DISP.2 (C2P)
unnamed: C61.1, DISP.3 (C2N)
unnamed: C62.1, DISP.4 (C1P)
unnamed: C62.2, DISP.5 (C1N)
unnamed: DISP.13 (/CS), R27.2
unnamed: IC17.5 (BST), R40.2
unnamed: IC17.8 (FB), R41.1
unnamed: C53.1, R40.1
unnamed: IC17.6 (EN), R37.2
unnamed: C52.1, IC17.7 (VCC), R44.1
unnamed: IC17.1 (AAM), R39.1, R44.2
unnamed: R46.2, T2.1 (G)
unnamed: DISP.27 (VCOMH), R28.1
unnamed: C65.1, DISP.28 (VCC)
unnamed: R49.2, T4.1 (G)
unnamed: C64.1, DISP.29 (VLSS)
RE-I1: I-SET.A, R24.2
RE-I2: I-SET.B, R25.2
RE-SWI: C43.1, I-SET.1, R26.2
RE-SWV: C44.1, R23.2, V-SET.1
RE-V1: R19.2, V-SET.A
RE-V2: R20.2, V-SET.B
SW1: C53.2, IC17.3 (SW), L3.1, SW3O.TP
VBUS: C51.1, C55.1, IC17.2 (IN), R37.1; also elsewhere on the board
VOUT-1: C63.1, MOSFET3.5 (D_2), MOSFET3.6 (D_3), MOSFET3.7 (D_4), MOSFET3.8 (D), MOSFET3.9 (D), MOSFET4.5 (D_2), MOSFET4.6 (D_3), MOSFET4.7 (D_4), MOSFET4.8 (D), MOSFET4.9 (D), R31.1, VOUT1.TP; also elsewhere on the board
VOUT-2: C7.1; also elsewhere on the board
VOUT-USB: C58.1, MOSFET4.1 (S_2), MOSFET4.2 (S_3), MOSFET4.3 (S), R48.1; also elsewhere on the board

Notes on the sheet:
VOLTAGE ENCODER
CURRENT ENCODER
3.3V OUTPUT DC-DC CONVERTER
Vin = 4.5-24V
POWER MOSFETS
3.3V-3A MAX OUT
5V/9V/15V/20V-3A MAX OUT
0.96 OLED
PSU CONTROL
Rev 1.0.0
David Sipos / DvidMakesThings
USB-Power Delivery PSU

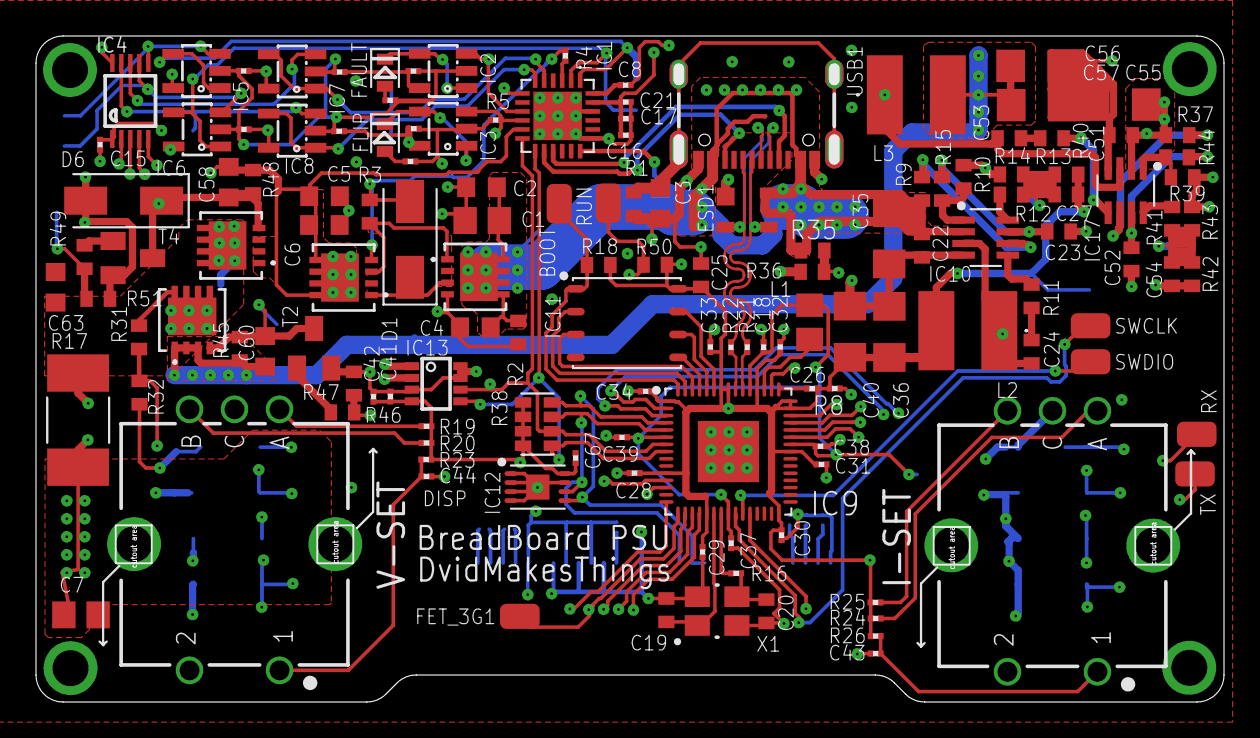
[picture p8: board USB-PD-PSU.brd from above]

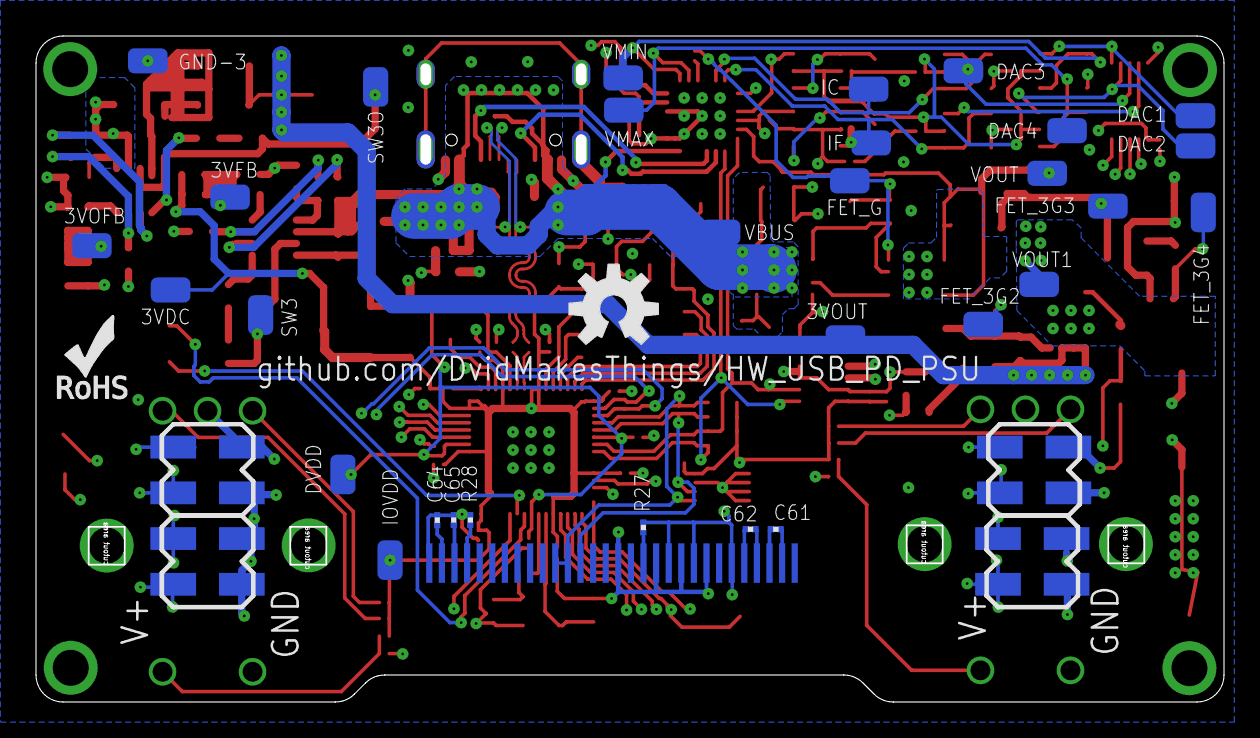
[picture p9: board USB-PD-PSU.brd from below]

Board: 4 copper layers, 66.0 x 37.0 mm, 176 parts (36 on the bottom side), 94 nets.

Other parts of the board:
U$1: ROHS_LOGO_0.18_IN
U$2: OSHW-LOGO-M

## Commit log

2025-03-13 Add initial project structure and documentation for USB-PD-PSU
    [USB-PD-PSU.sch]
2025-03-13 finished sch. Review needed
    [USB-PD-PSU.sch]
2025-03-14 PCB design ready
    [USB-PD-PSU.brd, USB-PD-PSU.sch, USB-PD-PSU_top_bom.csv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]

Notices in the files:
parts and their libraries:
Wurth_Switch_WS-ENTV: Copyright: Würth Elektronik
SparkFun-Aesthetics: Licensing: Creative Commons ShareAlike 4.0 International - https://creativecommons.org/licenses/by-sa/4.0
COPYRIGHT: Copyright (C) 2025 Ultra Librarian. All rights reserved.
